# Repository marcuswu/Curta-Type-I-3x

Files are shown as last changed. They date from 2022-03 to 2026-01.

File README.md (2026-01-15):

# Curta-Type-I-3x
[][cc-by-nc-sa]

3x scale Curta Type I for FDM 3D printing

Please see the [BOM](https://docs.google.com/spreadsheets/d/16EJePozXW-uC6UFISzyT2eMk7c8wh6v-EP5L1U8fzfM/edit?usp=sharing) for information about how to print the parts, what non-printed parts to gather, and suggestions on how to source them.

The manual should provide a rough idea how to assemble the calculator.
The [assembly video](https://youtu.be/zh2Z11miQ0w) should also help.

For additional questions and help, please [join us on Discord](https://discord.gg/k7JcmqUPjh)

## Contributions
The calculator itself was originally designed by [Curt Herzstark](https://en.wikipedia.org/wiki/Curt_Herzstark) and produced by Contina AG Mauren.

[mcmaven](https://www.thingiverse.com/mcmaven)'s [Curta Calculator Mods](https://www.thingiverse.com/thing:3126676) heavily inspired my changes to the carry levers. I highly recommend checking out his other changes too.

Anything under the Mods folder will have its own acknowledgements if not made by me.

## Supporting this work
This is a passion project and does not directly make me any money. Previously, I used Amazon Associates links in the Bill of Materials, but I have since removed those.

If you would like to show your support in a monetary way, you can [Buy Me a Coffee](https://www.buymeacoffee.com/MarcusWu)

## License
This work is licensed under a
[Creative Commons Attribution-NonCommercial-ShareAlike 4.0 International License][cc-by-nc-sa].

[][cc-by-nc-sa]

[cc-by-nc-sa]: http://creativecommons.org/licenses/by-nc-sa/4.0/
[cc-by-nc-sa-image]: https://licensebuttons.net/l/by-nc-sa/4.0/88x31.png
[cc-by-nc-sa-shield]: https://img.shields.io/badge/License-CC%20BY--NC--SA%204.0-lightgrey.svg

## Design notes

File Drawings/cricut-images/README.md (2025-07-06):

## Sizing ##
I had trouble importing the SVG format images into Cricut Design Space. Instead, I chose to use PNG images. Since they are rasterized, I exported them at a much higher resolution and then scaled them down after importing into Design Space. This ensures the cuts from a rasterized image are high quality.

To size them down to the correct size, I opened the SVG to determine the correct dimensions and then set the appropriate dimensions in Design Space before cutting.

| Filename | Sizing Dimension | Size |
| --- | --- | --- |
| input_digits.png | Height | 15 mm |
| lower_housing.png | Height | 11.4 mm  |
| result_dial.png | Height | 10.5 mm  |
| reversing_lever_arrows.png | Height | 24 mm |
| upper_outer_sleeve.png | Height | 62 mm |
| upper_housing_numbers.png  | Width | 224.8 mm |

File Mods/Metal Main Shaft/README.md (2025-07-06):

# Metal Main Crank Mod

This alteration is intended to alleviate issues with the main shaft breaking along the layer lines. The main shaft is removed from the 3D print models and replaced with a metal rod or tube (I used aluminum rod).

Print one of each file plus the 3 step drum pins from the non-modified Curta. Supports are needed for step_drum_top, step_drum_bottom, and rotation_blocker. The pins will likely require a brim and a bit of sanding after removing the brim.

## Parts and Tools Needed
* Conical Reamer for 1:50 3mm taper pins.
* 9mmx300mm rod or tube. If choosing tube, use at least a 1mm thick wall.
* M3x16mm Spring pin.
* Drill or drill press.
* 3mm drill bit.

## Preparing the Main Shaft / Axle
 * Cut the 300mm shaft down to 258mm. Use a narrow blade like a band saw or a pull saw. Keep the off cut.
 * Place the shaft into the top and bottom jigs with the build plate side down against your work surface or drill press table. Ensure that the jigs are fully seated against the top and bottom of the shaft.
 * Drill through the single vertical hole in the bottom jig's slanted surface with a 3mm bit. If using a hand drill, make sure you have a sacrificial piece of wood or other material below the jig.
 * Place the jig pin through the drilled hole to secure the shaft in place. All further drilling will be in reference to this hole in both distance and angle.
 * Turn the jigs over and rest them on the slanted faces ensuring the top jig remains fully seated on the shaft. Drill through the hole in the top of the shaft through the printed top jig with a 3mm bit.
 * Turn the jigs so that the two side holes in the bottom jig are upright and drill those two holes with the 3mm bit.
 * Use a small file or deburring tool to deburr all cuts and holes

## Assembly
 * Slide the rotation blocker over the bottom of the shaft past the first hole for the anti-reversal plate to the second hole (the first one drilled). Line up the drilled hole with the hole in the rotation blocker, and tap the spring pin into the hole to secure the rotation blocker to the main shaft.
 * Combine the step drum top and bottom using the same pins as with the non-modified Curta with some cyanoacrylate glue (superglue).
 * Glue the off cut of the main shaft into the offset hole in the top of the step drum.
 * Slide the completed step drum down the main shaft, aligning the hole in the wedge behind the teeth of the step drum with the hole above the rotation blocker which should be 90 degrees offset from the rotation blocker hole.
 * Holding the main shaft with the pin of the rotation blocker facing you and the flat side of the rotation blocker facing the left, rotate the step drum so that its the teeth are facing away from you.
 * Use the conical reamer to shape the hole in the printed part and the main shaft for the conical pin and tap the step drum pin into place. It should be secure, but don't use too much force.
 * Continue Curta assembly following the manual.
 * Towards the end of the build when afixing the crank to the main shaft, repeat use of the conical reamer and tap the main axle crank pin into place.
 * If disassembly is ever needed, tap the conical pins out in the opposite direction from the way they were installed.

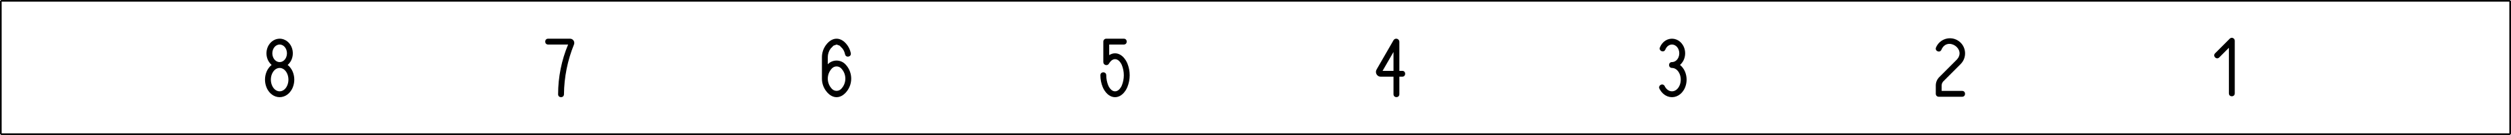
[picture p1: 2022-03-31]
Drawings/cricut-images/lower_housing.png

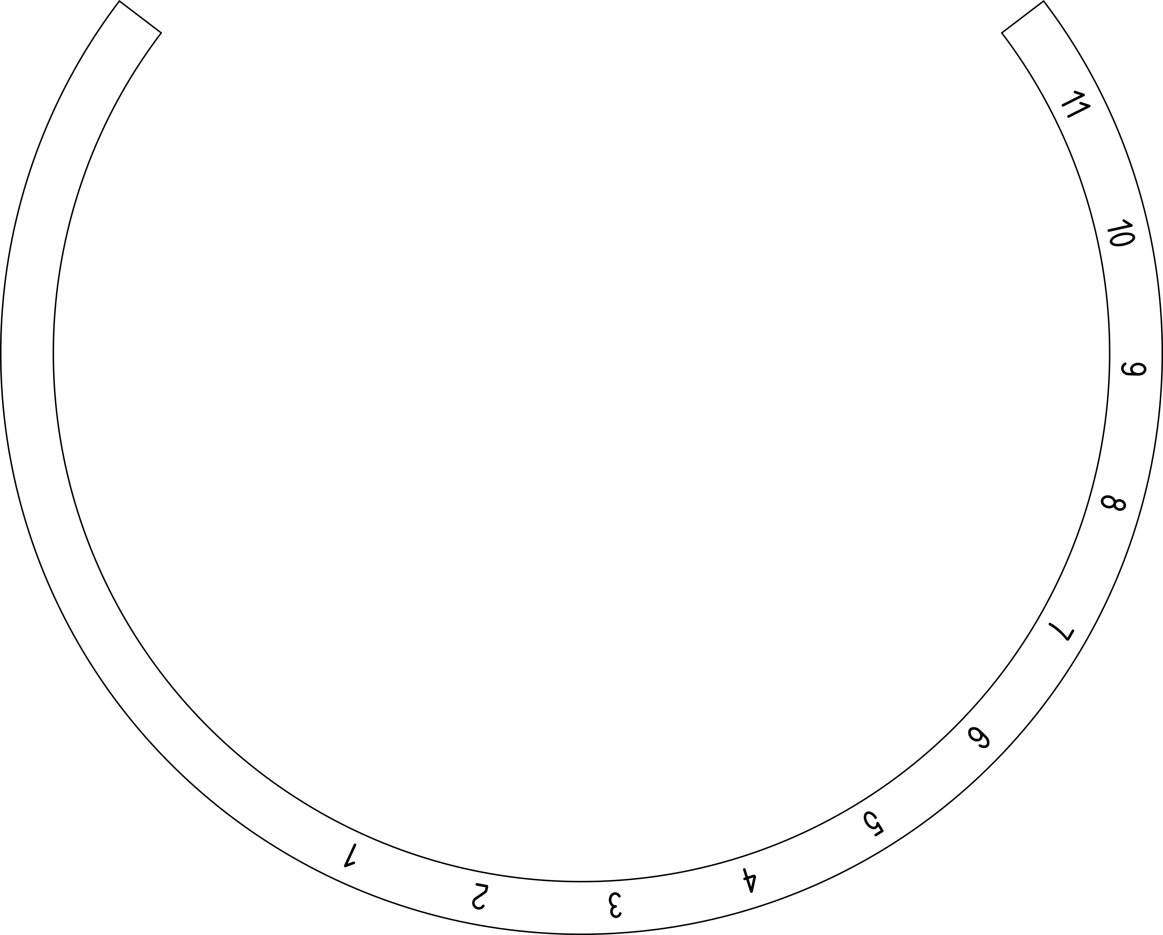
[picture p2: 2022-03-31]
Drawings/cricut-images/upper_housing_numbers.png

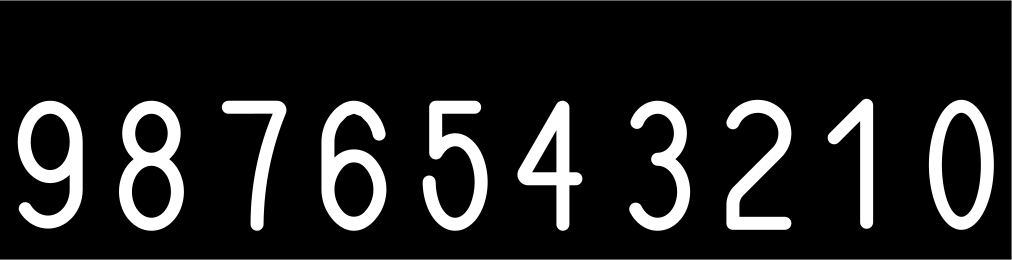
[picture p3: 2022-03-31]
Drawings/cricut-images/input_digits.png

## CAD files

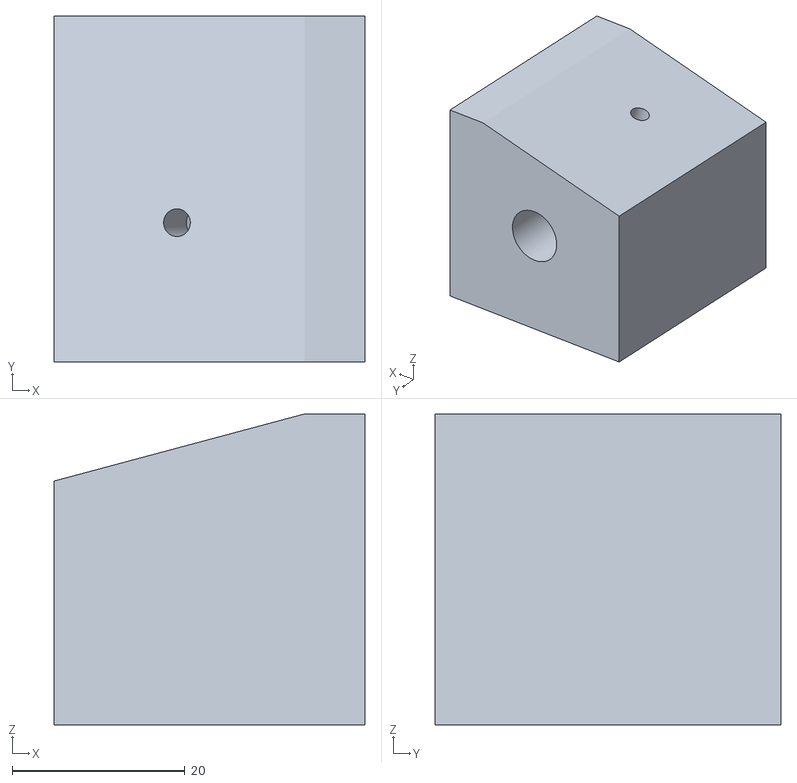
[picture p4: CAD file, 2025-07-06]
Mods/Metal Main Shaft/main_axle_drill_jig_top.stl
36.0 x 40.0 x 36.0

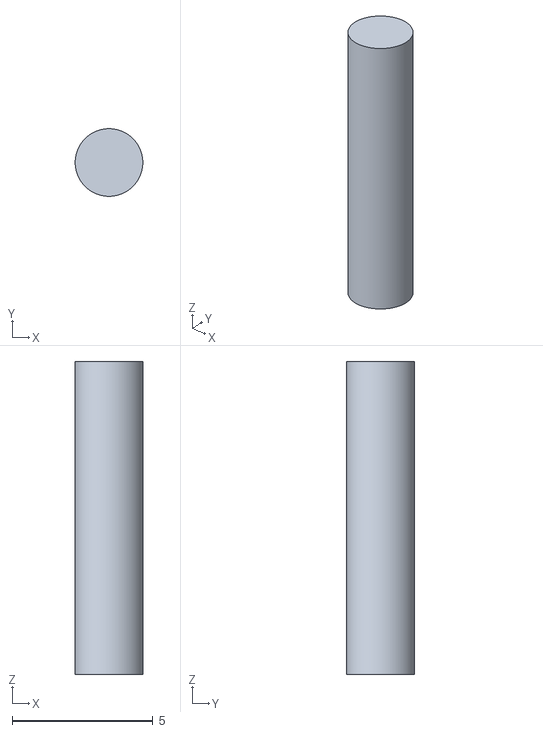
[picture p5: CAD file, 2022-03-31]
STLs/36 - Results Dials/number roll carry pin full x7.stl
2.40 x 2.40 x 11.1

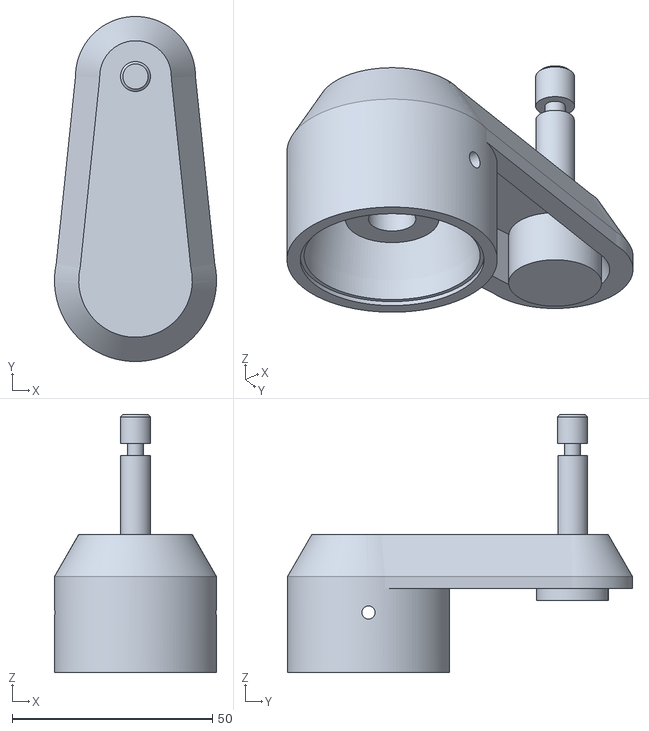
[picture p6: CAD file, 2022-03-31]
STLs/48 - Assemble Crank Handle/main crank.stl
40.5 x 86.2 x 64.5

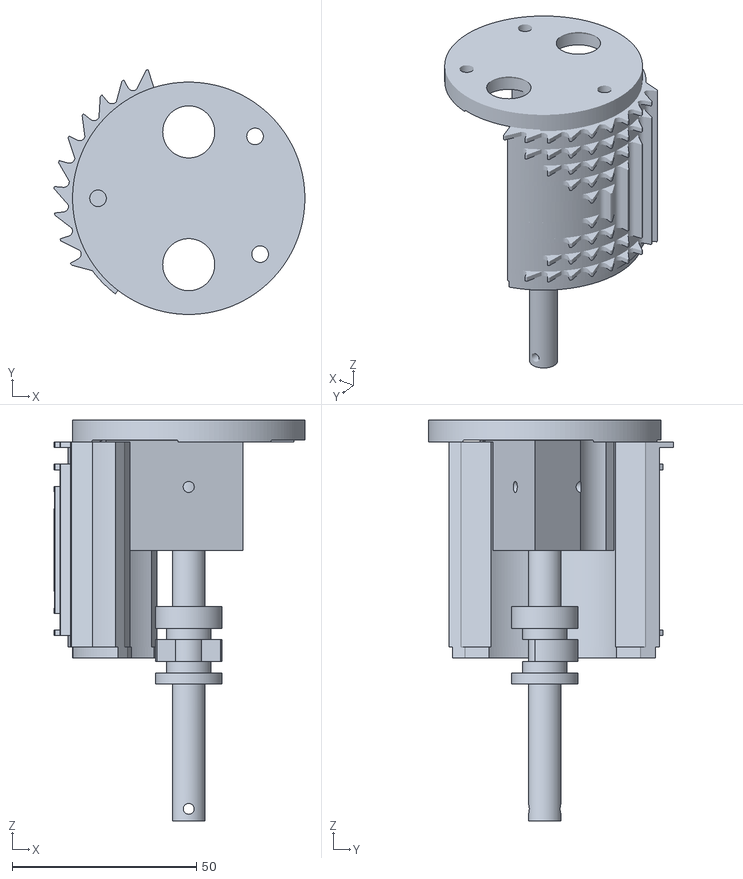
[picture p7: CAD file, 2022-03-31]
STLs/11 - Assemble Step Drum/main axle and step drum bottom.stl
68.0 x 66.4 x 108.8

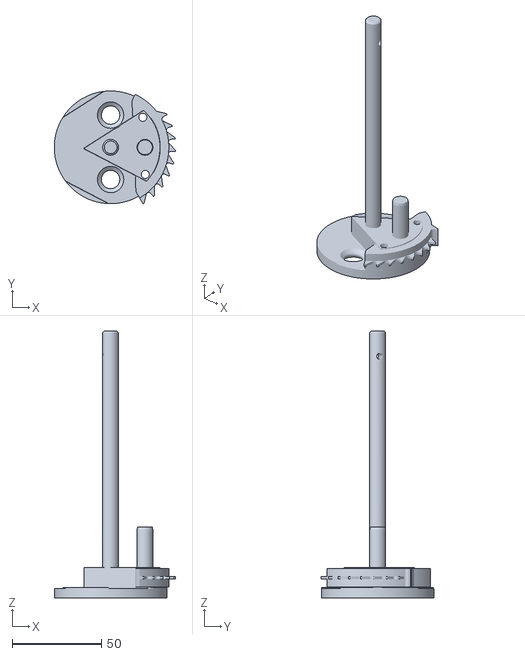
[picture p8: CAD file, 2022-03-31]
STLs/11 - Assemble Step Drum/main axle and step drum top.stl
67.9 x 63.2 x 149.2

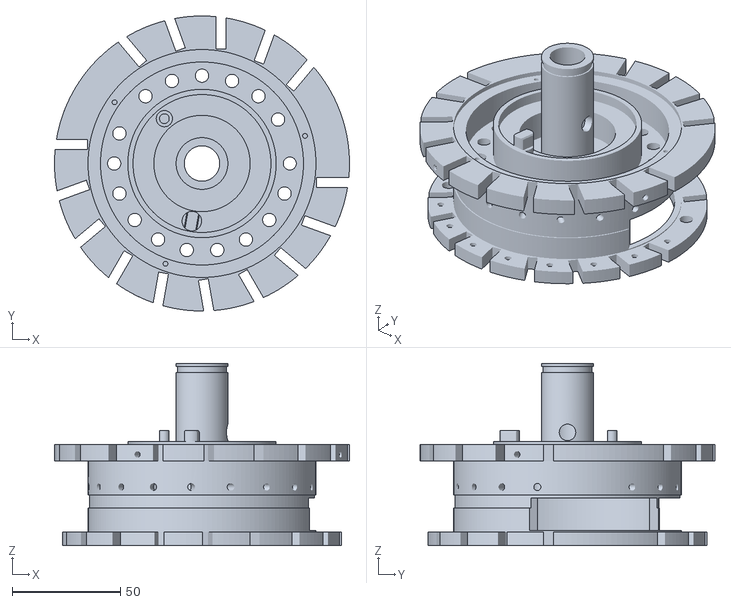
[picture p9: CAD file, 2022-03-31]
STLs/9 - Tens Bell & Main Body/main body.stl
136.1 x 136.0 x 84.0

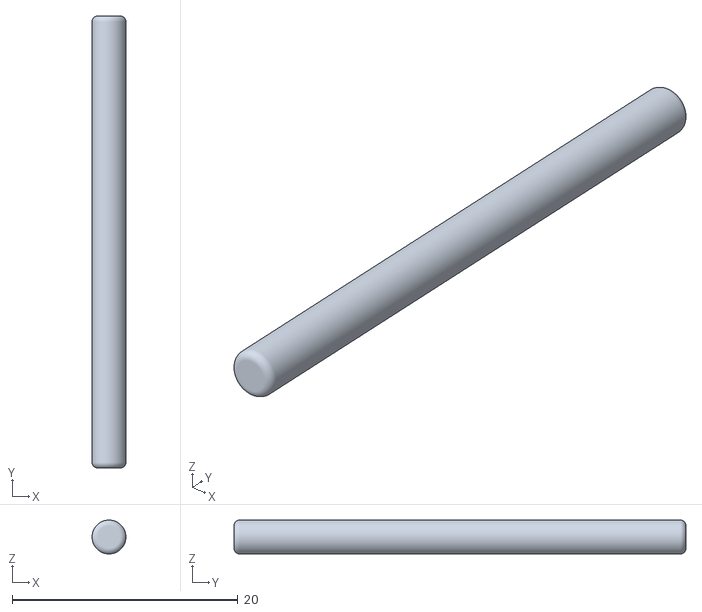
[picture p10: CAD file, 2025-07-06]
Mods/Metal Main Shaft/main_axle_drill_jig_pin.stl
3.00 x 40.0 x 3.00

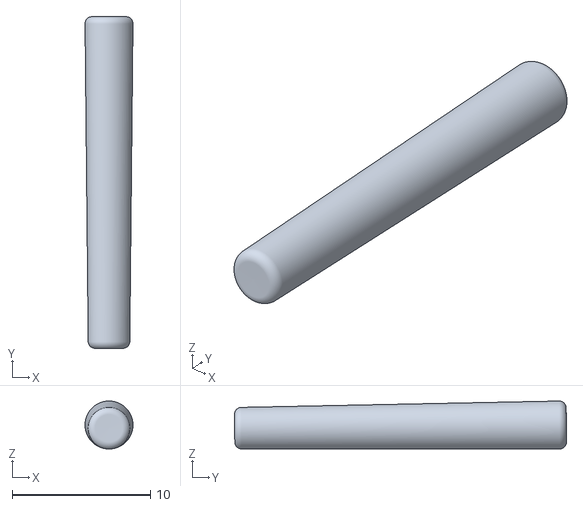
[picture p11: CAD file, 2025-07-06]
Mods/Metal Main Shaft/main_axle_step_drum_pin.stl
3.47 x 24.0 x 3.47

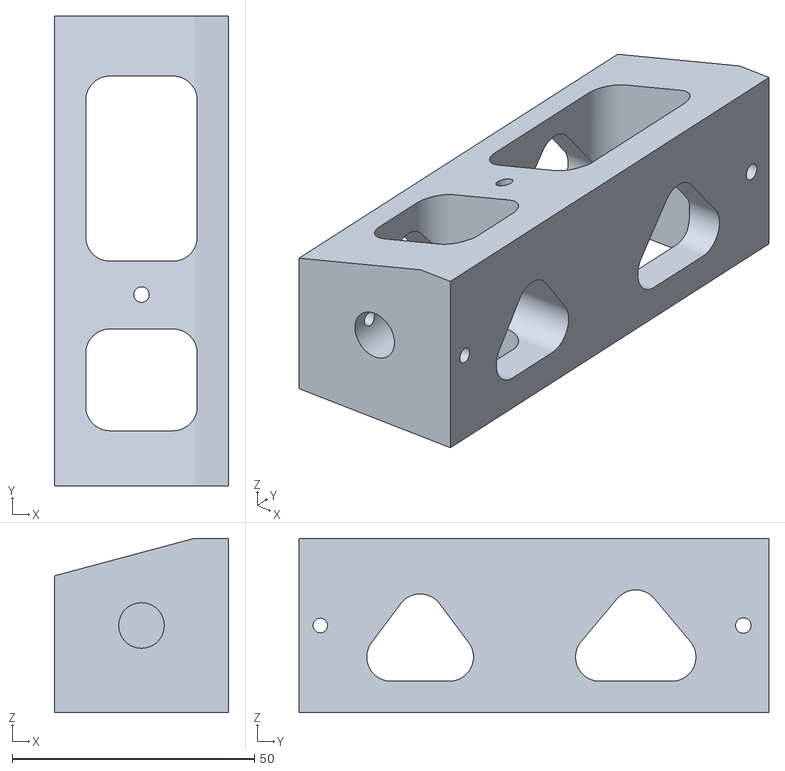
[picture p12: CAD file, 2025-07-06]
Mods/Metal Main Shaft/main_axle_drill_jig_bottom.stl
36.0 x 97.0 x 36.0

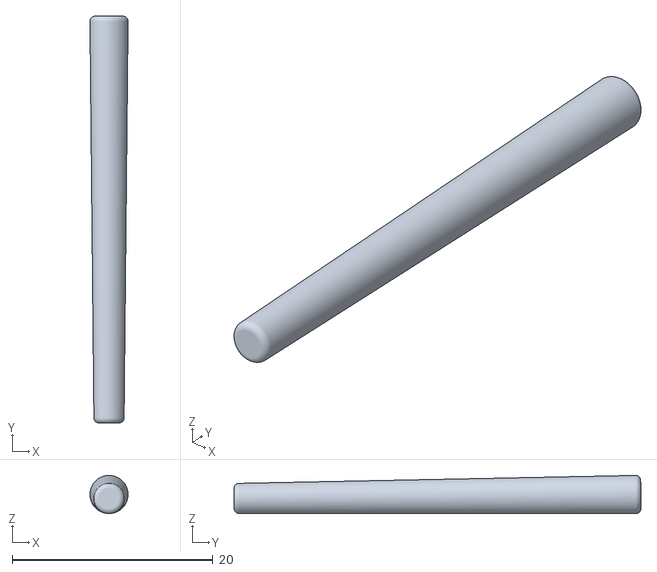
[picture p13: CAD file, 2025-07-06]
Mods/Metal Main Shaft/main_axle_crank_pin.stl
3.80 x 40.5 x 3.80

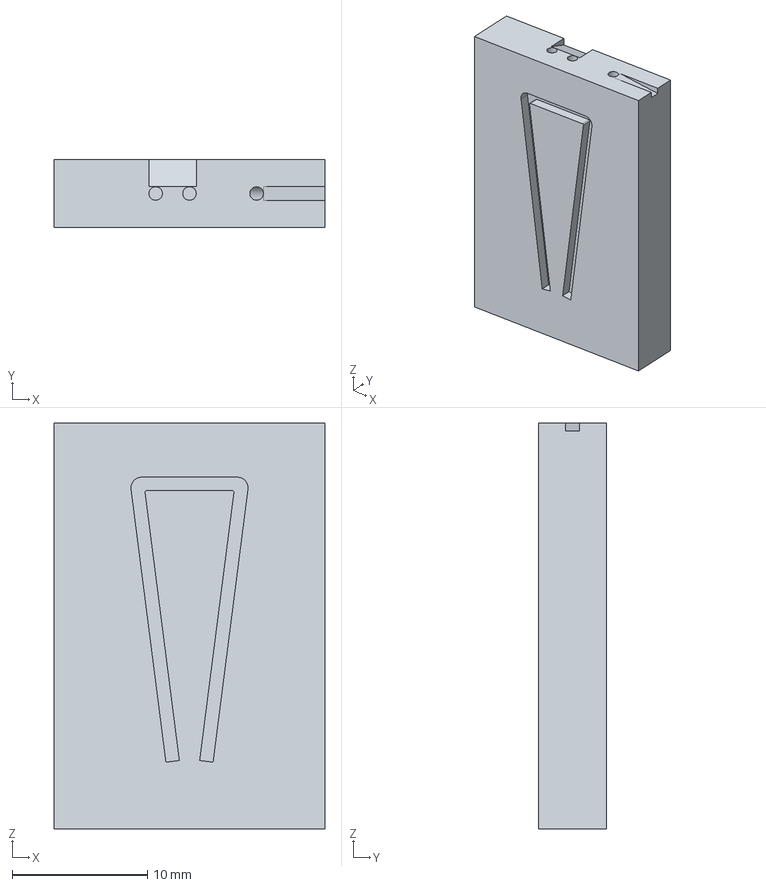
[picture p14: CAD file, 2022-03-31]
CAD/carry_lever_spring_tool.step
20.0 x 5.00 x 30.0 mm

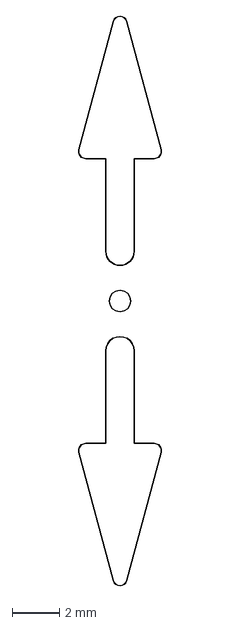
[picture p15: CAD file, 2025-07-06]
Manual/Painting/reversing lever arrows.dxf
3.52 x 24.0 mm

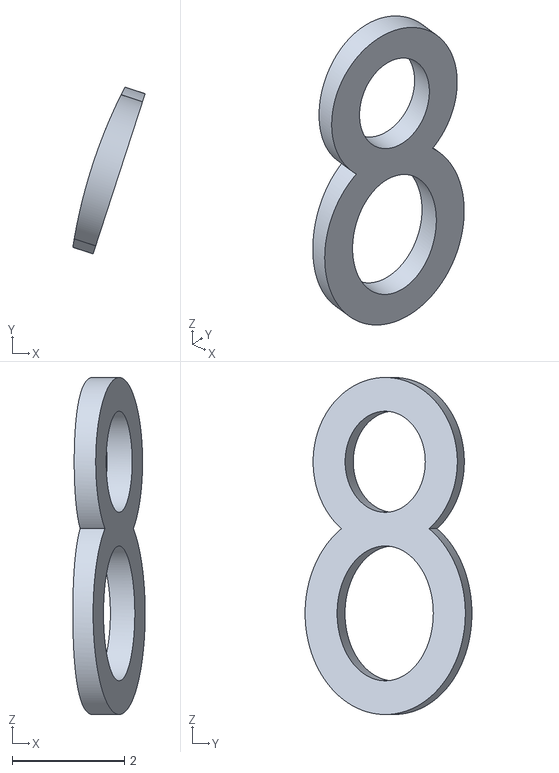
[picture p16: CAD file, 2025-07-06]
Mods/Printed Lettering/dials/results dial - digit 8.stl
1.29 x 2.97 x 6.00

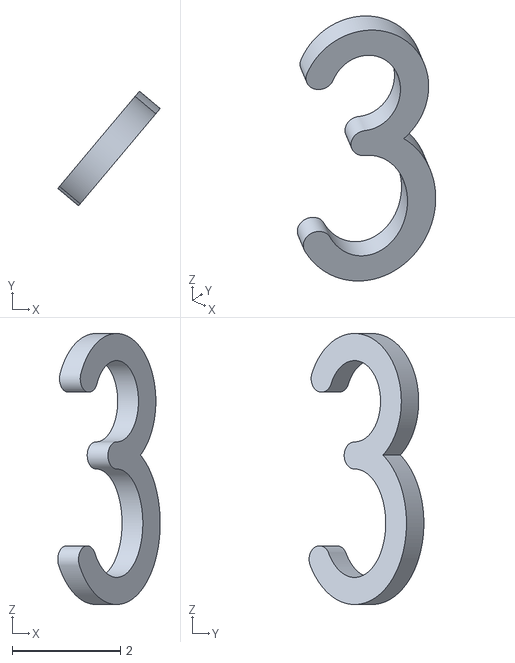
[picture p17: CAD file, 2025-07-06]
Mods/Printed Lettering/lower housing/Lower Housing - input 3.stl
1.89 x 2.12 x 5.00

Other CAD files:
Mods/Printed Lettering/selector shaft top/mmu selector shaft top.3mf
Mods/Printed Lettering/upper housing/upper housing - digit 7.stl
Mods/Printed Lettering/upper outer sleeve/upper outer sleeve - A.stl
STLs/10 - Upper Frame/frame support x3.stl
Manual/Painting/5mm digits.dxf
Manual/Painting/Bottom disc.dxf
Manual/Painting/Input Digits-exploded.dxf
Manual/Painting/Input Digits.dxf
Manual/Painting/results dial.dxf
Manual/Painting/reversing lever arrows-R15.dxf
Manual/Painting/reversing lever arrows-R21.dxf
Manual/Painting/reversing lever arrows.dwg
Manual/Painting/upper outer sleeve-cricut.dxf
Manual/Painting/upper outer sleeve.dxf
Mods/Metal Main Shaft/rotation_blocker.stl
Mods/Metal Main Shaft/step_drum_bottom.stl
Mods/Metal Main Shaft/step_drum_top.stl
Mods/Printed Lettering/dials/mmu results dial type 1.3mf
Mods/Printed Lettering/dials/mmu results dial type 2.3mf
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

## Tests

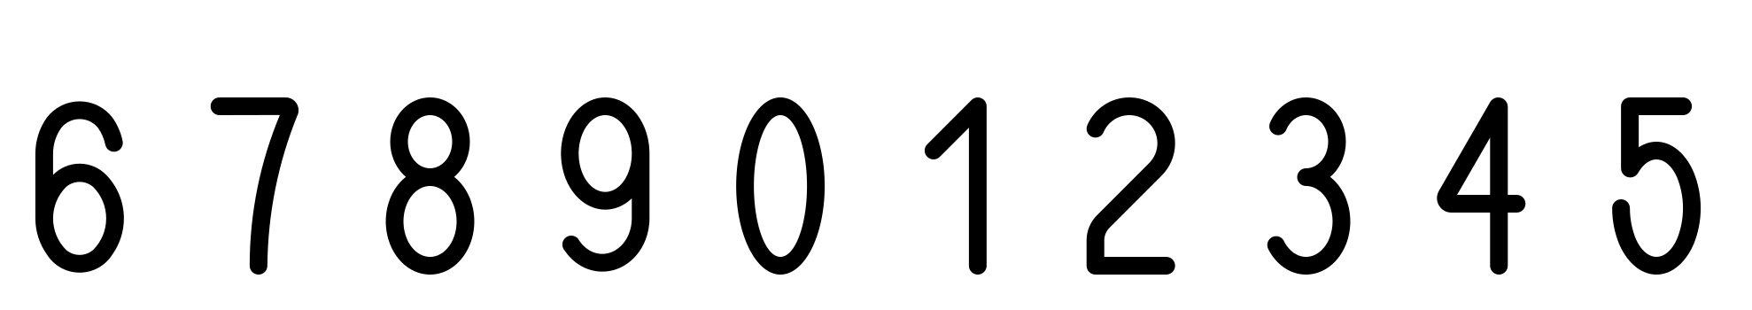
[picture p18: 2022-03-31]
Drawings/cricut-images/results_dial.png

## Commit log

2022-03-31 Restructuring of the entire project
    * Bringing the project to github
    * Rewrote the build manual
    * Reorganized STL files based on the manual
    * Renamed STL files to be more consistent
    * Added non-printed parts to the CAD assembly
    * Releasing STEP files
    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
    [10218.stl, 10219 - 410002.stl, 10220 - 410003 x15.stl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]
2025-07-06 Multiple updates (I've been bad about committing)
    * Add drawings, dxf for lettering
    * Add main shaft, lettering mods
    [5mm digits.dxf, Bottom disc.dxf, Input Digits-exploded.dxf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]

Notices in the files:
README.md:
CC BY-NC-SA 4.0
